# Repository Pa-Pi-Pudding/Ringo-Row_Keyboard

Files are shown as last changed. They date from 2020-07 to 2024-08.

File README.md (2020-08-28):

# Ringo-Row_Keyboard

## parts list
|name|rated value|number of articles|remarks|
|----|----|----|----|
|type-c connector|5v 12 pin| 2|http://akizukidenshi.com/catalog/g/gC-14356/|
|PolySwitch|1.35A | 2|http://akizukidenshi.com/catalog/g/gP-13013/|
|PRTR5V0U2X SOT-143|1GHz| 2|https://www.aitendo.com/product/15987|
|resistor|22 Ω| 4||
|resistor|5.1K Ω| 4||
|ResetSwitch| | 1| https://www.aitendo.com/product/10524|
|resistor | 10k Ω | 1 | |
|Crystal oscillator| 16Mhz 4pin| 1|http://akizukidenshi.com/catalog/g/gP-02457/|
|Chip capacitor | 22pF 1206 | 2| https://www.aitendo.com/product/15403|
|Chip capacitor | 0.1μF 1206| 3| http://akizukidenshi.com/catalog/g/gP-15180/|
|Chip capacitor | 1μF 1206 | 1| http://akizukidenshi.com/catalog/g/gP-15180/|
|Chip capacitor | 10μF 1206 | 1| http://akizukidenshi.com/catalog/g/gP-15180/|
|resistor | 1k Ω | 1 | |
|switching diode|100v 200mA| 72|http://akizukidenshi.com/catalog/g/gI-07783/|
|ATMega42u4 AUR| 5v| 1| http://akizukidenshi.com/catalog/g/gI-09835/|

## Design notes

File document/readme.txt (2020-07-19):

------------------------ガバット寸法-----------------------------------------
全部内径

プレート約 
長辺 282mm 
短辺 125mm

プレート角の弧の長さ
1.727 mm
半径 1.1m

キースイッチの穴(ALPSキースイッチがはまる大きさ)
外周61.6mm
長辺 16mm 
短辺 13mm

ねじ穴の円周 M2スペーサにハメるねじなので、M2ネジが入る大きさのasshole
7.536 mm
半径1.2 mm

スタビライザの四角
長辺 0.7mm
短辺 0.28mm (0.3)

enterとspaceの支えるやつ円周
20.096mm
半径3.2 mm

enterとspaceの支えるやつ四角の外周
2 mm × 2 mm
--------------------------------------------------------------------------------

-----------------------------------------板の厚さ-------------------------------

Top プレート 1.2mm
Bottom プレート 2.0mm

--------------------------------------------------------------------------------

-----------------------------------------よさげの板----------------------------

https://store.shopping.yahoo.co.jp/tugiteyasan/al-fp-12-800-600.html?sc_i=shp_pc_search_itemlist_shsrg_title

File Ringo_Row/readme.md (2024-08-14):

# RIngo_row
1. qmk_firmwareをpull
2. qmk_firmware/keyboardないにRingo-Rowを移動
3. make Ringo-Row:default

RIngo_row

*A short description of the keyboard/project*

* Keyboard Maintainer: [Pa_Pi_Pudding](https://github.com/yourusername)
* Hardware Supported: *The PCBs, controllers supported*
* Hardware Availability: *Links to where you can find this hardware*

Make example for this keyboard (after setting up your build environment):

    make RIngo_row:default

Flashing example for this keyboard:

    make RIngo_row:default:flash

See the [build environment setup](https://docs.qmk.fm/#/getting_started_build_tools) and the [make instructions](https://docs.qmk.fm/#/getting_started_make_guide) for more information. Brand new to QMK? Start with our [Complete Newbs Guide](https://docs.qmk.fm/#/newbs).

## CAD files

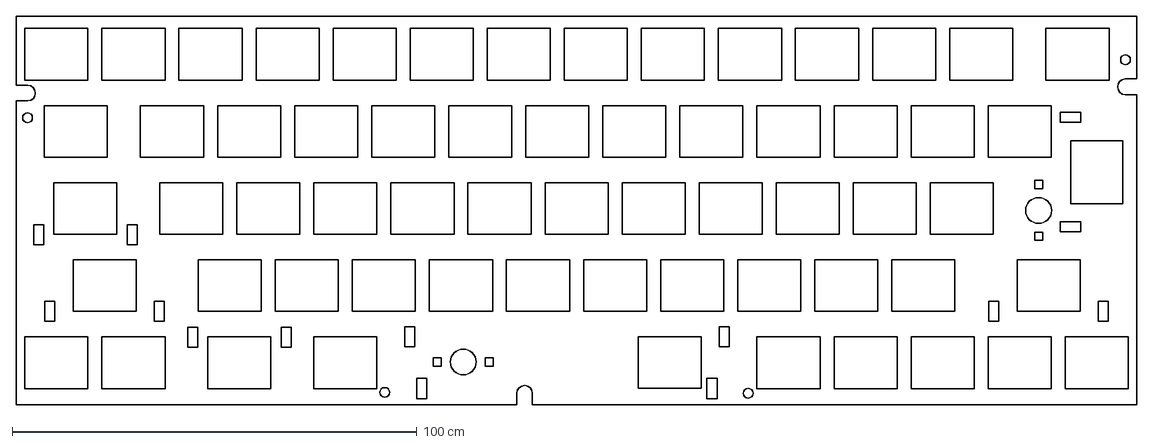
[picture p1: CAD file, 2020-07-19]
dxf/References/Y62 v1.dxf
277.0 x 96.0 cm

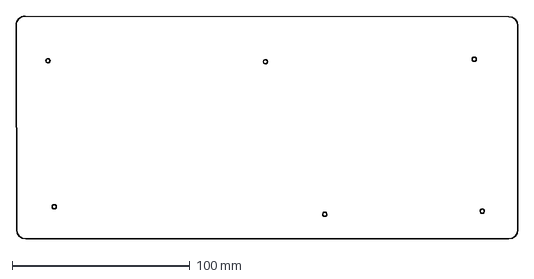
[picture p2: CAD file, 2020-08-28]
dxf/Ringo-Row-keyboard/Ringo-Row-keytboard_Bottom.dxf
282.5 x 125.3 mm

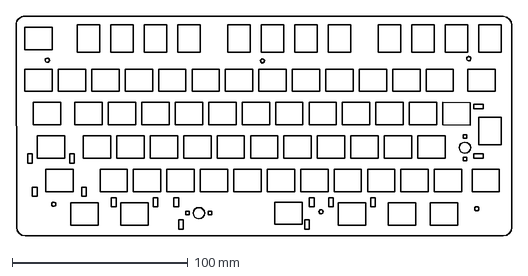
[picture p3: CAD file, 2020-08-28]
dxf/Ringo-Row-keyboard/Ringo-Row-keytboard_top.dxf
282.5 x 125.3 mm

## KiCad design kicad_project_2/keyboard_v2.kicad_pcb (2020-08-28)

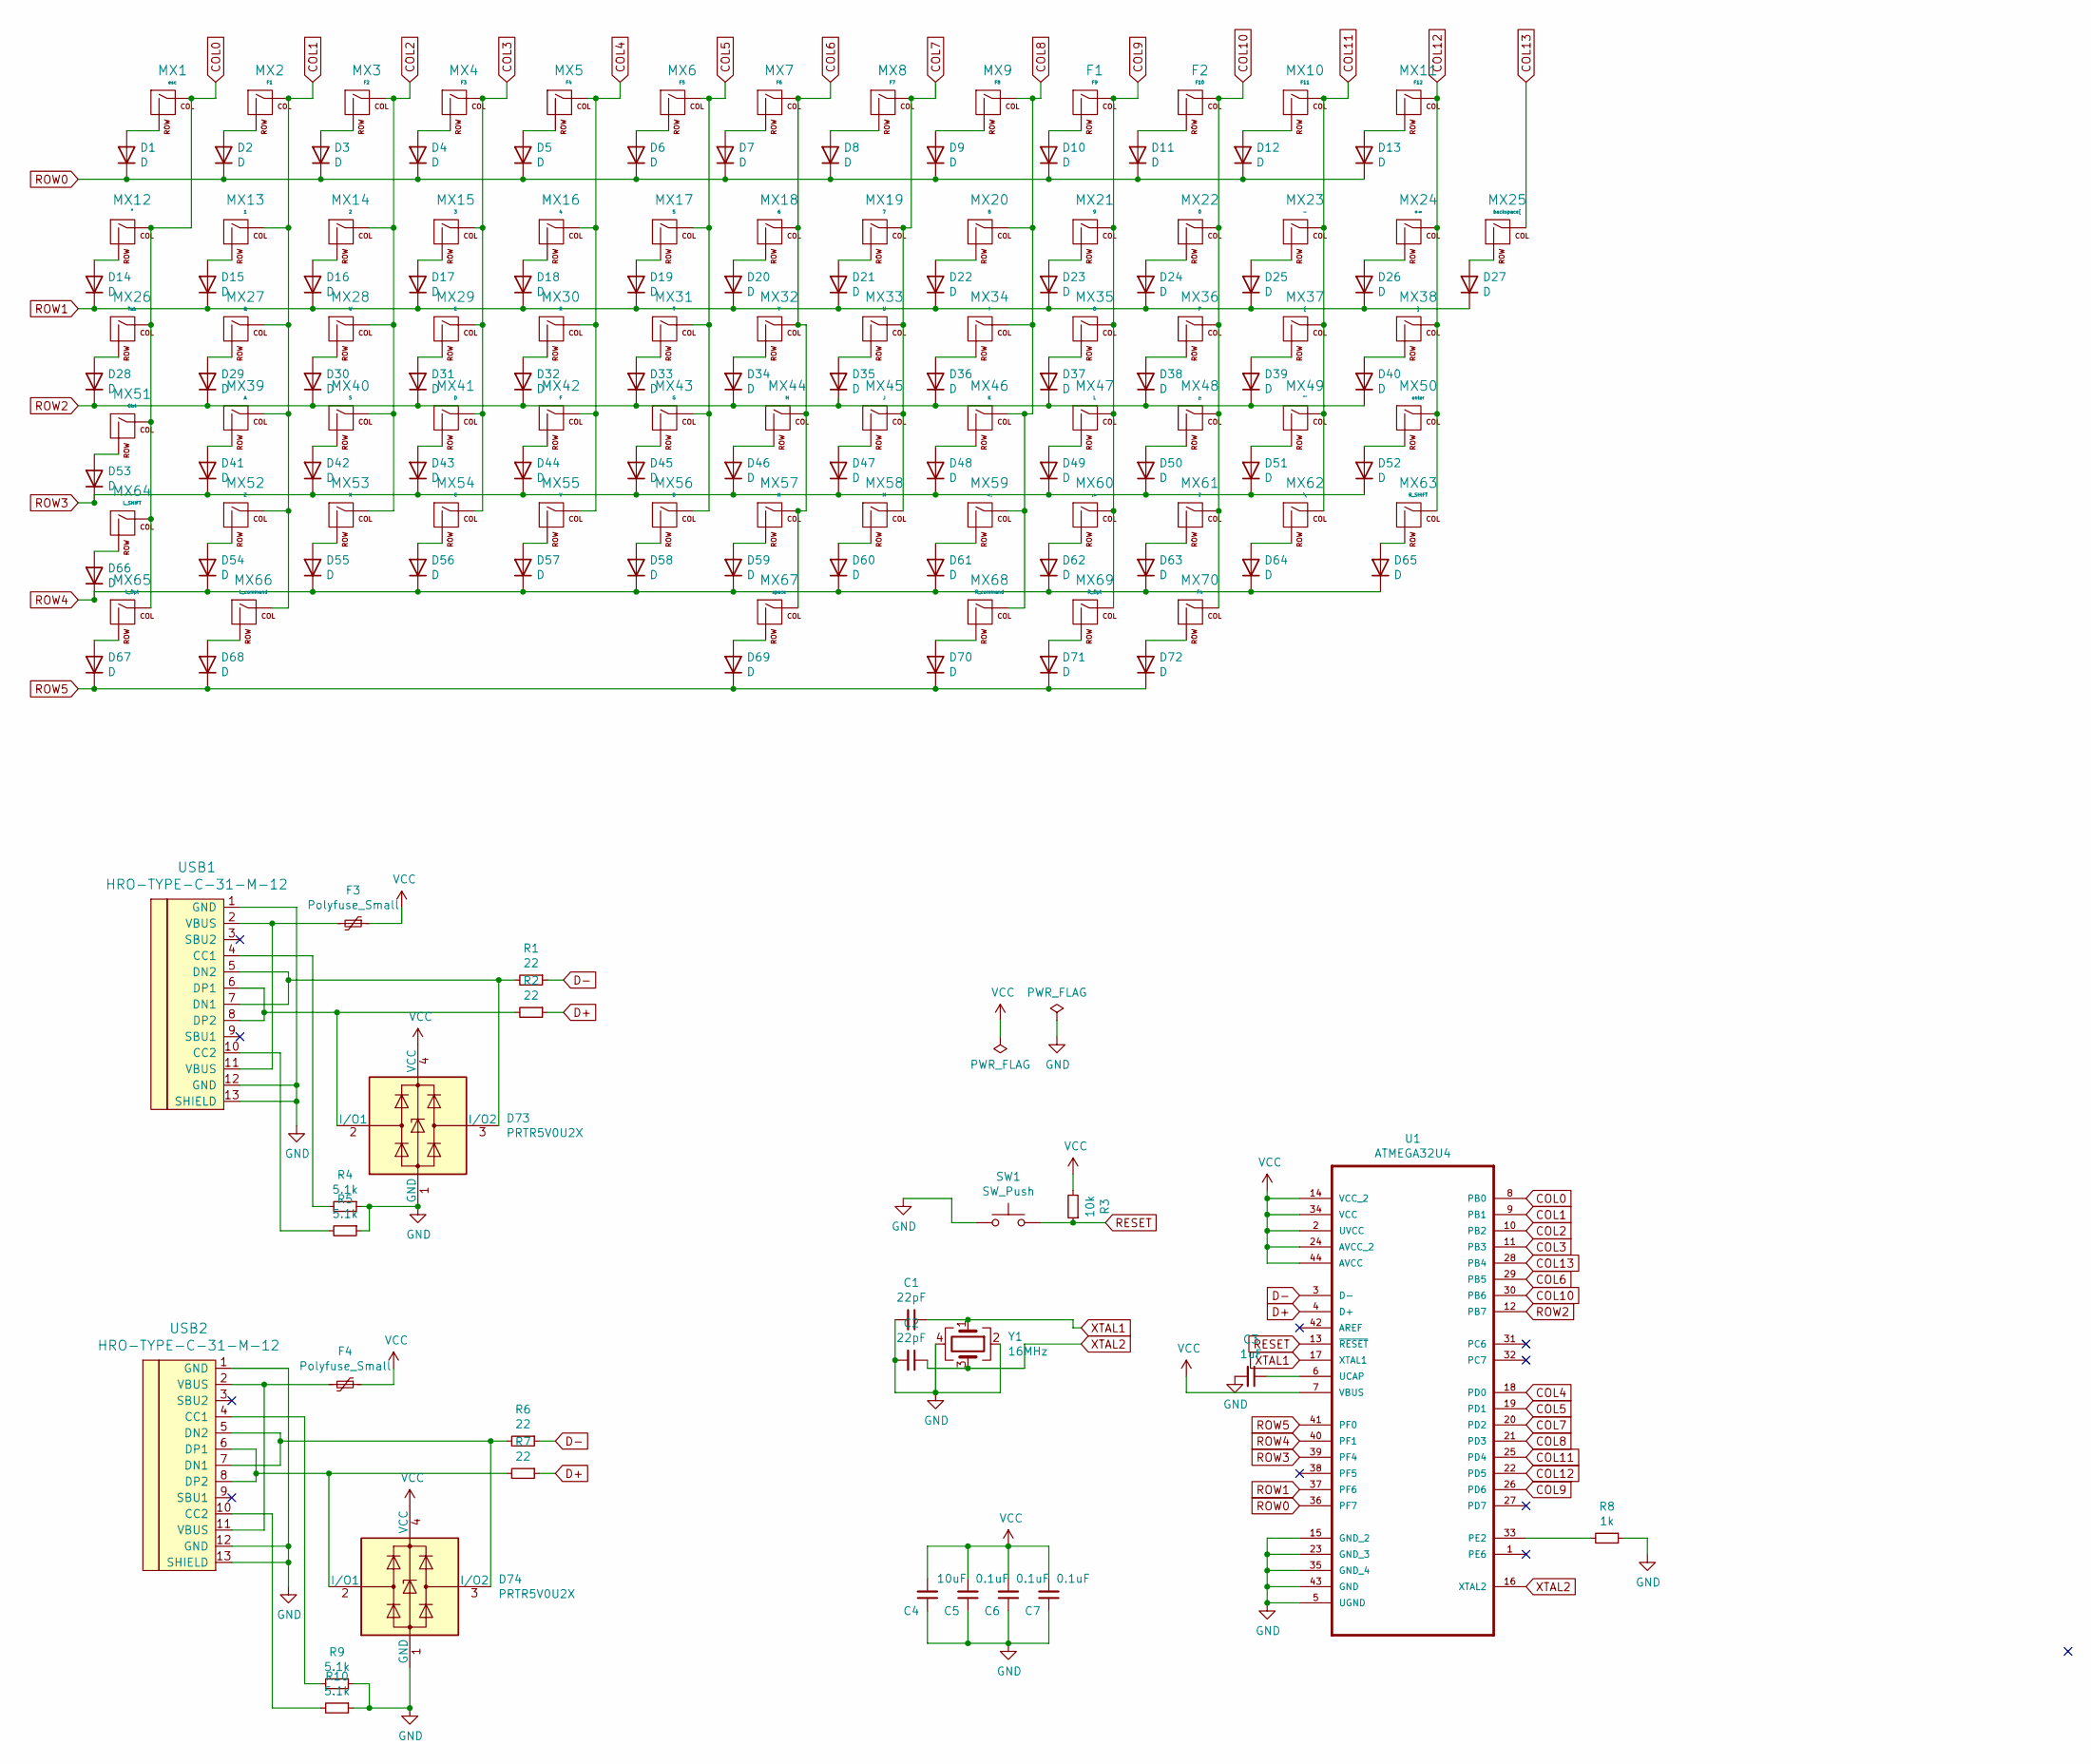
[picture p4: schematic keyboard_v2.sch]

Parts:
C1, C2: 22pF; C_1206_3216Metric_Pad1.42x1.75mm_HandSolder
C3: 1uF; D3_TH_SMD
C4: 10uF; D3_TH_SMD
C5, C6, C7: 0.1uF; D3_TH_SMD
D1, D2, D3, D4, D5, D6, D7, D8, D9, D10, D11, D12, D13, D14, D15, D16, D17, D18, D19, D20, D21, D22, D23, D24, D25, D26, D27, D28, D29, D30, D31, D32, D33, D34, D35, D36, D37, D38, D39, D40, D41, D42, D43, D44, D45, D46, D47, D48, D49, D50, D51, D52, D53, D54, D55, D56, D57, D58, D59, D60, D61, D62, D63, D64, D65, D66, D67, D68, D69, D70, D71, D72: D; D3_TH_SMD
D73, D74: PRTR5V0U2X; SOT-143_Handsoldering
F1: F9; ALPS-1U
F2: F10; ALPS-1U
F3, F4: Polyfuse_Small; D3_TH_SMD
MX1: esc; ALPS-1U
MX2: F1; ALPS-1U
MX3: F2; ALPS-1U
MX4: F3; ALPS-1U
MX5: F4; ALPS-1U
MX6: F5; ALPS-1U
MX7: F6; ALPS-1U
MX8: F7; ALPS-1U
MX9: F8; ALPS-1U
MX10: F11; ALPS-1U
MX11: F12; ALPS-1U
MX12: ~^; ALPS-1U
MX13: 1; ALPS-1U
MX14: 2; ALPS-1U
MX15: 3; ALPS-1U
MX16: 4; ALPS-1U
MX17: 5; ALPS-1U
MX18: 6; ALPS-1U
MX19: 7; ALPS-1U
MX20: 8; ALPS-1U
MX21: 9; ALPS-1U
MX22: 0; ALPS-1U
MX23: -; ALPS-1U
MX24: +=; ALPS-1U
MX25: backspace[; ALPS-1U
MX26: Tab; ALPS-1U
MX27: Q; ALPS-1U
MX28: W; ALPS-1U
MX29: E; ALPS-1U
MX30: R; ALPS-1U
MX31: T; ALPS-1U
MX32: Y; ALPS-1U
MX33: U; ALPS-1U
MX34: I; ALPS-1U
MX35: O; ALPS-1U
MX36: P; ALPS-1U
MX37: [; ALPS-1U
MX38: ]; ALPS-1U
MX39: A; ALPS-1U
MX40: S; ALPS-1U
MX41: D; ALPS-1U
MX42: F; ALPS-1U
MX43: G; ALPS-1U
MX44: H; ALPS-1U
MX45: J; ALPS-1U
MX46: K; ALPS-1U
MX47: L; ALPS-1U
MX48: :;; ALPS-1U
MX49: \"'; ALPS-1U
MX50: enter; ALPS-1U
MX51: Ctrl; ALPS-1U
MX52: Z; ALPS-1U
MX53: X; ALPS-1U
MX54: C; ALPS-1U
MX55: V; ALPS-1U
MX56: B; ALPS-1U
MX57: N; ALPS-1U
MX58: M; ALPS-1U
MX59: <,; ALPS-1U
MX60: .>; ALPS-1U
MX61: ?; ALPS-1U
MX62: \\; ALPS-1U
MX63: R_SHIFT; ALPS-1U
MX64: L_SHIFT; ALPS-1U
MX65: L_Opt; ALPS-1U
MX66: L_command; ALPS-1U
MX67: space; ALPS-1U
MX68: R_command; ALPS-1U
MX69: R_Opt; ALPS-1U
MX70: Fn; ALPS-1U
R1, R2, R6, R7: 22; D3_TH_SMD
R3: 10k; D3_TH_SMD
R4, R5, R9, R10: 5.1k; D3_TH_SMD
R8: 1k; D3_TH_SMD
SW1: SW_Push; SW_Tactile_SPST_Angled_PTS645Vx39-2LFS
U1: ATMEGA32U4; ATmega32U4
USB1, USB2: HRO-TYPE-C-31-M-12; HRO-TYPE-C-31-M-12-HandSoldering
Y1: 16MHz; Crystal_SMD_3225-4Pin_3.2x2.5mm_HandSoldering

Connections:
COL0: MX1.1 (COL), MX12.1 (COL), MX26.1 (COL), MX51.1 (COL), MX64.1 (COL), MX65.1 (COL), U1.8 (PB0)
COL1: MX2.1 (COL), MX13.1 (COL), MX27.1 (COL), MX39.1 (COL), MX52.1 (COL), MX66.1 (COL), U1.9 (PB1)
COL2: MX3.1 (COL), MX14.1 (COL), MX28.1 (COL), MX40.1 (COL), MX53.1 (COL), U1.10 (PB2)
COL3: MX4.1 (COL), MX15.1 (COL), MX29.1 (COL), MX41.1 (COL), MX54.1 (COL), U1.11 (PB3)
COL4: MX5.1 (COL), MX16.1 (COL), MX30.1 (COL), MX42.1 (COL), MX55.1 (COL), U1.18 (PD0)
COL5: MX6.1 (COL), MX17.1 (COL), MX31.1 (COL), MX43.1 (COL), MX56.1 (COL), U1.19 (PD1)
COL6: MX7.1 (COL), MX18.1 (COL), MX32.1 (COL), MX44.1 (COL), MX57.1 (COL), MX67.1 (COL), U1.29 (PB5)
COL7: MX8.1 (COL), MX19.1 (COL), MX33.1 (COL), MX45.1 (COL), MX58.1 (COL), U1.20 (PD2)
COL8: MX9.1 (COL), MX20.1 (COL), MX34.1 (COL), MX46.1 (COL), MX59.1 (COL), MX68.1 (COL), U1.21 (PD3)
COL9: F1.1 (COL), MX21.1 (COL), MX35.1 (COL), MX47.1 (COL), MX60.1 (COL), MX69.1 (COL), U1.26 (PD6)
COL10: F2.1 (COL), MX22.1 (COL), MX36.1 (COL), MX48.1 (COL), MX61.1 (COL), MX70.1 (COL), U1.30 (PB6)
COL11: MX10.1 (COL), MX23.1 (COL), MX37.1 (COL), MX49.1 (COL), MX62.1 (COL), U1.25 (PD4)
COL12: MX11.1 (COL), MX24.1 (COL), MX38.1 (COL), MX50.1 (COL), MX63.1 (COL), U1.22 (PD5)
COL13: MX25.1 (COL), U1.28 (PB4)
D+: R2.1, R7.1, U1.4 (D+)
D-: R1.1, R6.1, U1.3 (D-)
GND: C1.2, C2.2, C3.2, C4.1, C5.1, C6.1, C7.1, D73.1 (GND), D74.1 (GND), R4.1, R5.1, R8.1, R9.1, R10.1, SW1.1, U1.5 (UGND), U1.15 (GND_2), U1.23 (GND_3), U1.35 (GND_4), U1.43 (GND), USB1.1 (GND), USB1.12 (GND), USB1.13 (SHIELD), USB2.1 (GND), USB2.12 (GND), USB2.13 (SHIELD), Y1.2, Y1.4
unnamed: C3.1, U1.6 (UCAP)
unnamed: D1.2 (A), MX1.2 (ROW)
unnamed: D2.2 (A), MX2.2 (ROW)
unnamed: D3.2 (A), MX3.2 (ROW)
unnamed: D4.2 (A), MX4.2 (ROW)
unnamed: D5.2 (A), MX5.2 (ROW)
unnamed: D6.2 (A), MX6.2 (ROW)
unnamed: D7.2 (A), MX7.2 (ROW)
unnamed: D8.2 (A), MX8.2 (ROW)
unnamed: D9.2 (A), MX9.2 (ROW)
unnamed: D10.2 (A), F1.2 (ROW)
unnamed: D11.2 (A), F2.2 (ROW)
unnamed: D12.2 (A), MX10.2 (ROW)
unnamed: D13.2 (A), MX11.2 (ROW)
unnamed: D14.2 (A), MX12.2 (ROW)
unnamed: D15.2 (A), MX13.2 (ROW)
unnamed: D16.2 (A), MX14.2 (ROW)
unnamed: D17.2 (A), MX15.2 (ROW)
unnamed: D18.2 (A), MX16.2 (ROW)
unnamed: D19.2 (A), MX17.2 (ROW)
unnamed: D20.2 (A), MX18.2 (ROW)
unnamed: D21.2 (A), MX19.2 (ROW)
unnamed: D22.2 (A), MX20.2 (ROW)
unnamed: D23.2 (A), MX21.2 (ROW)
unnamed: D24.2 (A), MX22.2 (ROW)
unnamed: D25.2 (A), MX23.2 (ROW)
unnamed: D26.2 (A), MX24.2 (ROW)
unnamed: D27.2 (A), MX25.2 (ROW)
unnamed: D28.2 (A), MX26.2 (ROW)
unnamed: D29.2 (A), MX27.2 (ROW)
unnamed: D30.2 (A), MX28.2 (ROW)
unnamed: D31.2 (A), MX29.2 (ROW)
unnamed: D32.2 (A), MX30.2 (ROW)
unnamed: D33.2 (A), MX31.2 (ROW)
unnamed: D34.2 (A), MX32.2 (ROW)
unnamed: D35.2 (A), MX33.2 (ROW)
unnamed: D36.2 (A), MX34.2 (ROW)
unnamed: D37.2 (A), MX35.2 (ROW)
unnamed: D38.2 (A), MX36.2 (ROW)
unnamed: D39.2 (A), MX37.2 (ROW)
unnamed: D40.2 (A), MX38.2 (ROW)
unnamed: D41.2 (A), MX39.2 (ROW)
unnamed: D42.2 (A), MX40.2 (ROW)
unnamed: D43.2 (A), MX41.2 (ROW)
unnamed: D44.2 (A), MX42.2 (ROW)
unnamed: D45.2 (A), MX43.2 (ROW)
unnamed: D46.2 (A), MX44.2 (ROW)
unnamed: D47.2 (A), MX45.2 (ROW)
unnamed: D48.2 (A), MX46.2 (ROW)
unnamed: D49.2 (A), MX47.2 (ROW)
unnamed: D50.2 (A), MX48.2 (ROW)
unnamed: D51.2 (A), MX49.2 (ROW)
unnamed: D52.2 (A), MX50.2 (ROW)
unnamed: D53.2 (A), MX51.2 (ROW)
unnamed: D54.2 (A), MX52.2 (ROW)
unnamed: D55.2 (A), MX53.2 (ROW)
unnamed: D56.2 (A), MX54.2 (ROW)
unnamed: D57.2 (A), MX55.2 (ROW)
unnamed: D58.2 (A), MX56.2 (ROW)
unnamed: D59.2 (A), MX57.2 (ROW)
unnamed: D60.2 (A), MX58.2 (ROW)
unnamed: D61.2 (A), MX59.2 (ROW)
unnamed: D62.2 (A), MX60.2 (ROW)
unnamed: D63.2 (A), MX61.2 (ROW)
unnamed: D64.2 (A), MX62.2 (ROW)
unnamed: D65.2 (A), MX63.2 (ROW)
unnamed: D66.2 (A), MX64.2 (ROW)
unnamed: D67.2 (A), MX65.2 (ROW)
unnamed: D68.2 (A), MX66.2 (ROW)
unnamed: D69.2 (A), MX67.2 (ROW)
unnamed: D70.2 (A), MX68.2 (ROW)
unnamed: D71.2 (A), MX69.2 (ROW)
unnamed: D72.2 (A), MX70.2 (ROW)
unnamed: D73.2 (I/O1), R2.2, USB1.6 (DP1), USB1.8 (DP2)
unnamed: D73.3 (I/O2), R1.2, USB1.5 (DN2), USB1.7 (DN1)
unnamed: D74.2 (I/O1), R7.2, USB2.6 (DP1), USB2.8 (DP2)
unnamed: D74.3 (I/O2), R6.2, USB2.5 (DN2), USB2.7 (DN1)
unnamed: F3.2, USB1.2 (VBUS), USB1.11 (VBUS)
unnamed: F4.2, USB2.2 (VBUS), USB2.11 (VBUS)
unnamed: R4.2, USB1.4 (CC1)
unnamed: R5.2, USB1.10 (CC2)
unnamed: R8.2, U1.33 (PE2)
unnamed: R9.2, USB2.4 (CC1)
unnamed: R10.2, USB2.10 (CC2)
RESET: R3.1, SW1.2, U1.13 (~RESET)
ROW0: D1.1 (K), D2.1 (K), D3.1 (K), D4.1 (K), D5.1 (K), D6.1 (K), D7.1 (K), D8.1 (K), D9.1 (K), D10.1 (K), D11.1 (K), D12.1 (K), D13.1 (K), U1.36 (PF7)
ROW1: D14.1 (K), D15.1 (K), D16.1 (K), D17.1 (K), D18.1 (K), D19.1 (K), D20.1 (K), D21.1 (K), D22.1 (K), D23.1 (K), D24.1 (K), D25.1 (K), D26.1 (K), D27.1 (K), U1.37 (PF6)
ROW2: D28.1 (K), D29.1 (K), D30.1 (K), D31.1 (K), D32.1 (K), D33.1 (K), D34.1 (K), D35.1 (K), D36.1 (K), D37.1 (K), D38.1 (K), D39.1 (K), D40.1 (K), U1.12 (PB7)
ROW3: D41.1 (K), D42.1 (K), D43.1 (K), D44.1 (K), D45.1 (K), D46.1 (K), D47.1 (K), D48.1 (K), D49.1 (K), D50.1 (K), D51.1 (K), D52.1 (K), D53.1 (K), U1.39 (PF4)
ROW4: D54.1 (K), D55.1 (K), D56.1 (K), D57.1 (K), D58.1 (K), D59.1 (K), D60.1 (K), D61.1 (K), D62.1 (K), D63.1 (K), D64.1 (K), D65.1 (K), D66.1 (K), U1.40 (PF1)
ROW5: D67.1 (K), D68.1 (K), D69.1 (K), D70.1 (K), D71.1 (K), D72.1 (K), U1.41 (PF0)
VCC: C4.2, C5.2, C6.2, C7.2, D73.4 (VCC), D74.4 (VCC), F3.1, F4.1, R3.2, U1.2 (UVCC), U1.7 (VBUS), U1.14 (VCC_2), U1.24 (AVCC_2), U1.34 (VCC), U1.44 (AVCC)
XTAL1: C1.1, U1.17 (XTAL1), Y1.1
XTAL2: C2.1, U1.16 (XTAL2), Y1.3

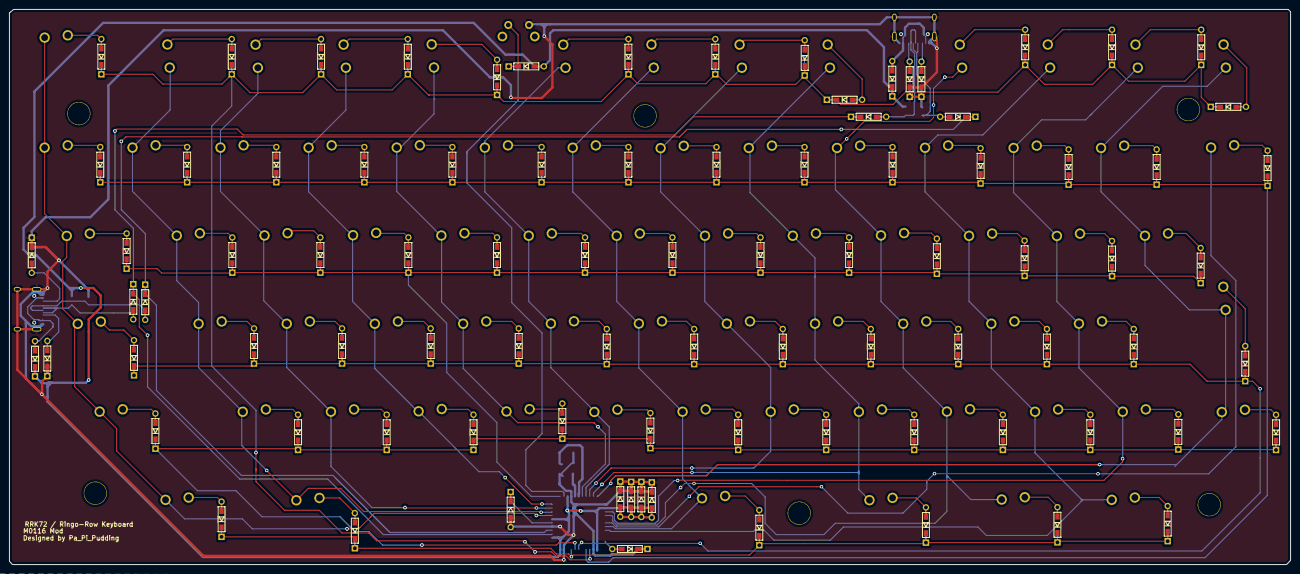
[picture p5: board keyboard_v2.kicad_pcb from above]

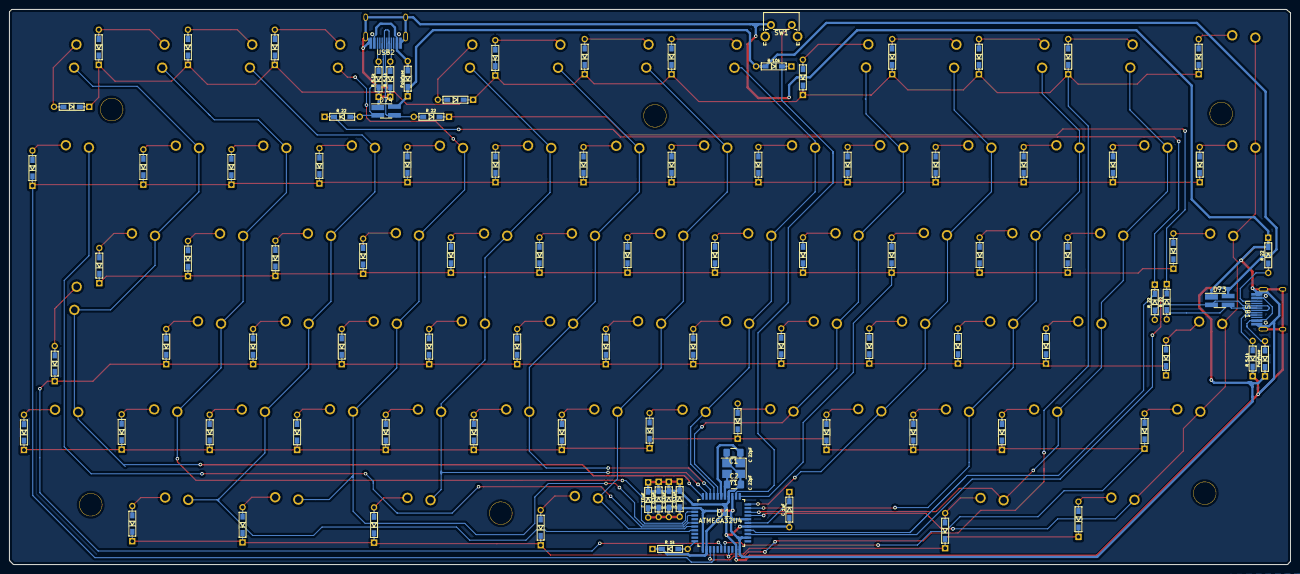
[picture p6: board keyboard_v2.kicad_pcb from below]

Board: 2 copper layers, 277.2 x 120.1 mm, 176 parts (97 on the bottom side), 111 nets.

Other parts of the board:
-: Val**; HOLE
.: Val**; HOLE
Ref**: Val**; HOLE
Ref**#2, Ref**#3, Ref**#4: Val**; HOLE

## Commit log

2020-07-19 fix readme
    [keyboard_v2.kicad_pcb]
2020-07-19 fix pcb
    [keyboard_v2.kicad_pcb, keyboard_v2.sch]
2020-08-01 add dxf
    [Ringo-Row-keyboard v13 8.dxf, Ringo-Row-keyboard v13 v4.dxf, Ringo-Row-keyboard_bottom v1.dxf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]
2020-08-28 fix parts list
    [Ringo-Row-keytboard_Bottom.dxf, Ringo-Row-keytboard_top.dxf, keyboard_v2.kicad_pcb]
